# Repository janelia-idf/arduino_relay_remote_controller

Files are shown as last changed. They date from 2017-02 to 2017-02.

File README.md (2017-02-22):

#arduino_relay_remote_controller

Authors:

    Peter Polidoro <polidorop@janelia.hhmi.org>

License:

    BSD

##firmware

Contains the Arduino firmware files. See firmware/README.rst

##host

Contains the code for controlling with a host computer.

###python

See host/python/README.rst

##pcb

Contains the pcb Kicad and gerber files.

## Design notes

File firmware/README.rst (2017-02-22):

Arduino Relay Remote Controller Device Firmware
-----------------------------------------------

Arduino firmware for the arduino_relay_remote_controller device.

For see the INSTALL.rst for installation instructions.

arduino_relay_remote_controller device firmware may be freely distributed
and modified in accordance with the License.

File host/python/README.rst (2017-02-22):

===============================
arduino_relay_remote_controller
===============================

arduino_relay_remote_controller is a python package to control the
Arduino relay remote controller over USB, using the python module, the
command line, or a webpage using a webserver.

Install
-------

See INSTALL.rst

Python Module
-------------

If installed into a python virtual environment, first activate it::

    source ~/virtualenvs/arduino_relay_remote_controller/bin/activate

Use ipython to run or test::

    ipython

Typical usage from an ipython shell often looks like this::

    from arduino_relay_remote_controller import ArduinoRelayRemoteController, ArduinoRelayRemoteControllers

    relay_remote_controllers = ArduinoRelayRemoteControllers()
    device_count = len(relay_remote_controllers)
    if device_count == 0:
        raise RuntimeError('No Arduino relay remote controllers detected, check connections.')
    relay_remote_controllers[0].getDevInfo()

    rrc = relay_remote_controllers[0]
    rrc.getCmds()
    # turn on all relays
    rrc.setAllRelaysOn()
    # turn off all relays
    rrc.setAllRelaysOff()
    # turn on relay 12
    rrc.setRelayOn(12)
    # turn off relay 12
    rrc.setRelayOff(12)
    # turn all board 0 relays on
    rrc.setAllBoardRelaysOn(0)
    # turn all board 0 relays off
    rrc.setAllBoardRelaysOff(0)
    # turn on relay 2 on board 1
    rrc.setBoardRelayOn(1,2)
    # turn on relay 2 on board 1
    rrc.setBoardRelayOff(1,2)

Web Page Controls
-----------------

Open a terminal and run::

    arduino_relay_remote_controller_webserver.py

Open a browser and navigate to::

    http://localhost:5000

Author: Peter Polidoro

This program is free software: you can redistribute it and/or modify
it under the terms of the GNU Lesser General Public License as published by
the Free Software Foundation, either version 3 of the License, or
(at your option) any later version.

This program is distributed in the hope that it will be useful,
but WITHOUT ANY WARRANTY; without even the implied warranty of
MERCHANTABILITY or FITNESS FOR A PARTICULAR PURPOSE.  See the
GNU Lesser General Public License for more details.

You should have received a copy of the GNU Lesser General Public License
along with this program.  If not, see <http://www.gnu.org/licenses/>.

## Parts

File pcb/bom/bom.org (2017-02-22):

# Bill of Materials
| ! | part    | description                      | vendor      | part number      | quantity |   cost |
|---+---------+----------------------------------+-------------+------------------+----------+--------|
|   | PCB     | arduino_relay_remote_control     | pcbuniverse | 1.3              |        1 |   1.00 |
|   | C1      | CAP CER 1UF 25V 10% X7R 1210     | digikey     | 445-13383-1-ND   |        1 |   0.84 |
|   | C2-3    | CAP CER 0.1UF 50V 10% X7R 1210   | digikey     | 478-3586-1-ND    |        2 |   0.39 |
|   | D1-17   | LED GREEN CLEAR 0805 SMD         | digikey     | 160-1179-1-ND    |       17 |   0.35 |
|   | P1      | CONN PWR JACK DC 2.5X5.5 8A T/H  | digikey     | CP-063BH-ND      |        1 |   1.78 |
|   | P1      | POWER SUPPLY SWITCHER 101W 24V   | digikey     | 271-2731-ND      |        1 |  81.38 |
|   | P1      | LINE CORD 3 COND US              | digikey     | 993-1039-ND      |        1 |   3.18 |
|   | P2-3    | CONN MOD JACK R/A 8P8C           | digikey     | RJSAE508002-ND   |        2 |   3.15 |
|   | R1-17   | RES 1.00K OHM 1/2W 1% 1210 SMD   | digikey     | 541-1.00KAACT-ND |       17 |   0.29 |
|   | SHIELD1 | BOARD MCU MEGA2560               | digikey     | 1050-1018-ND     |        1 |  51.91 |
|   | SHIELD1 | CONN HDR VERT 50POS .100" SNGL   | digikey     | SAM1055-50-ND    |        2 |   3.42 |
|   | U1      | IC SW SMART OCTAL LOWSIDE PDSO24 | digikey     | TLE7230GCT-ND    |        2 |   4.62 |
|---+---------+----------------------------------+-------------+------------------+----------+--------|
| # | total   |                                  |             |                  |          | 174.13 |
#+TBLFM: @14$7=(@I$quantity..@II$quantity)*(@I$cost..@II$cost);%.2f;N

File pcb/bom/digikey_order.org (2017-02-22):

# Bill of Materials
| quantity | part number      | ! | part    | description                      | vendor  |   cost |
|----------+------------------+---+---------+----------------------------------+---------+--------|
|       10 | 445-13383-1-ND   |   | C1      | CAP CER 1UF 25V 10% X7R 1210     | digikey |   0.84 |
|       20 | 478-3586-1-ND    |   | C2-3    | CAP CER 0.1UF 50V 10% X7R 1210   | digikey |   0.39 |
|      200 | 160-1179-1-ND    |   | D1-17   | LED GREEN CLEAR 0805 SMD         | digikey |   0.35 |
|       10 | CP-063BH-ND      |   | P1      | CONN PWR JACK DC 2.5X5.5 8A T/H  | digikey |   1.78 |
|       20 | RJSAE508002-ND   |   | P2-3    | CONN MOD JACK R/A 8P8C           | digikey |   3.15 |
|      200 | 541-1.00KAACT-ND |   | R1-17   | RES 1.00K OHM 1/2W 1% 1210 SMD   | digikey |   0.29 |
|       20 | SAM1055-50-ND    |   | SHIELD1 | CONN HDR VERT 50POS .100" SNGL   | digikey |   3.42 |
|       20 | TLE7230GCT-ND    |   | U1      | IC SW SMART OCTAL LOWSIDE PDSO24 | digikey |   4.62 |
|----------+------------------+---+---------+----------------------------------+---------+--------|
|          |                  | # | total   |                                  |         | 170.95 |
#+TBLFM: @10$7=(@I$quantity..@II$quantity)*(@I$cost..@II$cost);%.2f;N

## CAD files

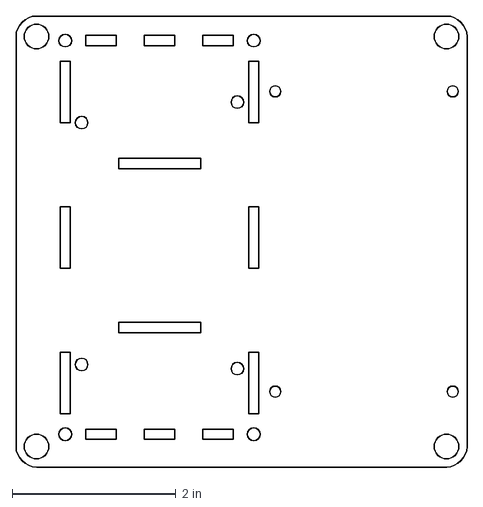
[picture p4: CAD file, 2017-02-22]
enclosure/arduino_relay_remote_controller_enclosure_display.25in.dxf
5.50 x 5.50 in

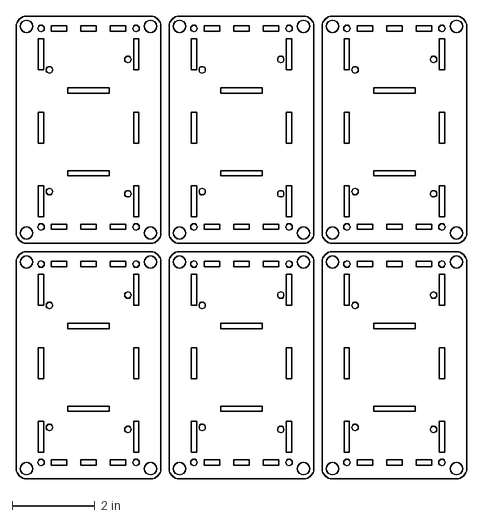
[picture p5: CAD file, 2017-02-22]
enclosure/arduino_relay_remote_controller_enclosure.25in.array.dxf
10.9 x 11.2 in

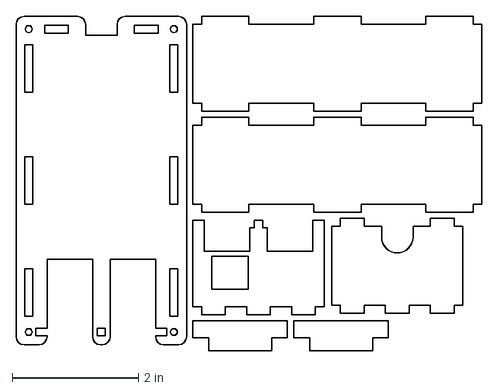
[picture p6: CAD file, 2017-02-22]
enclosure/arduino_relay_remote_controller_enclosure.125in.dxf
7.38 x 5.29 in

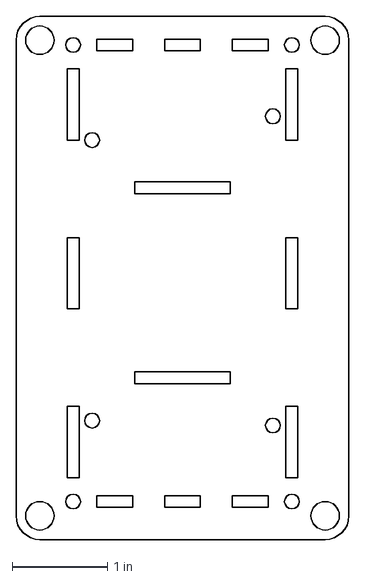
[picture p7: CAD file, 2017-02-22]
enclosure/arduino_relay_remote_controller_enclosure.25in.dxf
3.50 x 5.50 in

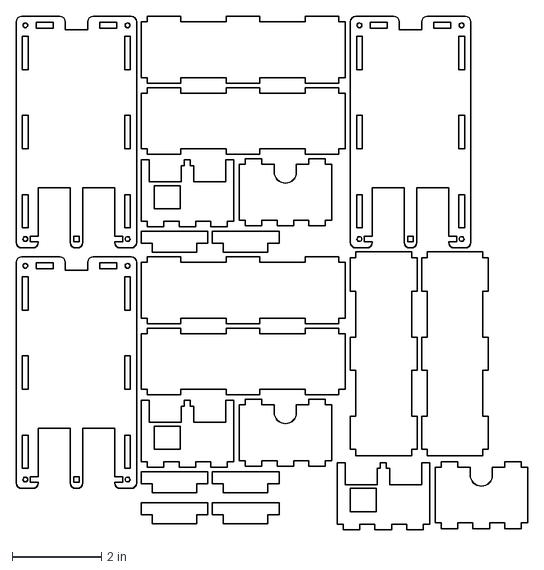
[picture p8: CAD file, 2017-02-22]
enclosure/arduino_relay_remote_controller_enclosure.125in.array.dxf
11.5 x 11.5 in

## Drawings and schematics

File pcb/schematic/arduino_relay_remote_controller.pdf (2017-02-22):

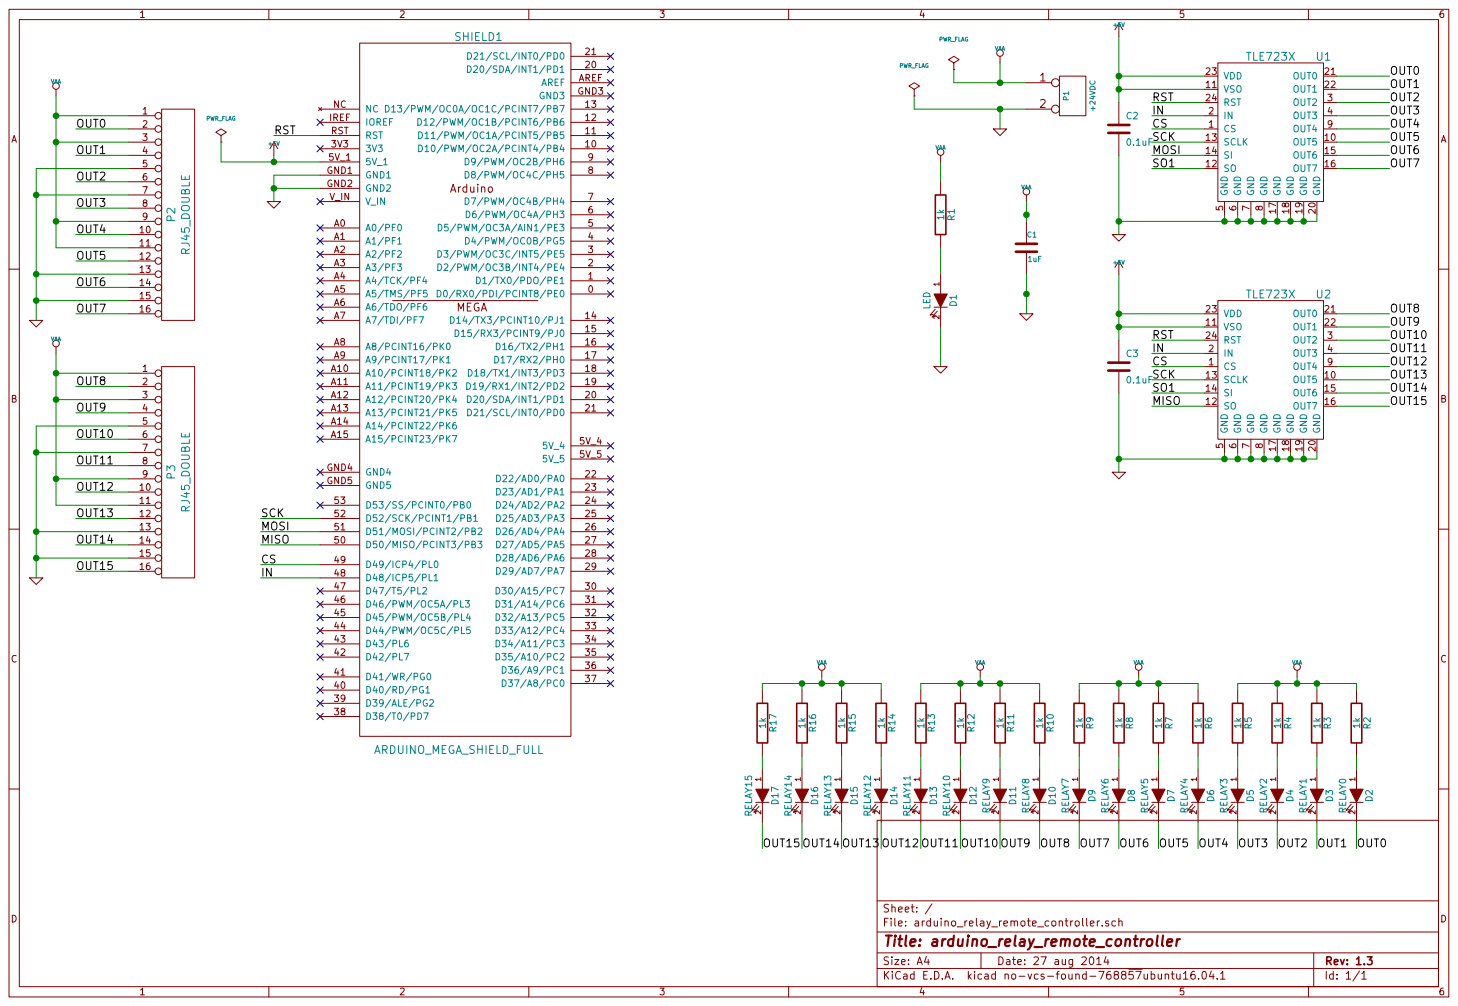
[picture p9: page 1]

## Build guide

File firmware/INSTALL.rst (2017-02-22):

Firmware installation instructions
-----------------------------------

Requirements:

The following libraries should be placed in the arduino sketchbook libraries
directory.

* Streaming              https://bitbucket.org/peterpolidoro/arduino_libs/src
* SerialReceiver         https://bitbucket.org/peterpolidoro/arduino_libs/src
* DictPrinter            https://bitbucket.org/peterpolidoro/arduino_libs/src
* Tle7232g               https://bitbucket.org/peterpolidoro/arduino_libs/src

Build and upload the firmware using the Arduino IDE.

see http://arduino.cc/en/Guide/Environment for instructions on using the IDE.

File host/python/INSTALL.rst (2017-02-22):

arduino_relay_remote_controller installation instructions
------------------------------------------------------

* Create a new virtual environment if necessary::

    virtualenv --system-site-packages ~/virtualenvs/arduino_relay_remote_controller

* Activate a virtual environment::

    source ~/virtualenvs/arduino_relay_remote_controller/bin/activate

* Install dependencies::

    pip install flask --upgrade
    pip install flask-sijax --upgrade

* Clone bitbucket mercurial repositories::

    mkdir ~/mercurial
    cd ~/mercurial
    hg clone https://bitbucket.org/peterpolidoro/python_libs/
    hg clone https://bitbucket.org/peterpolidoro/arduino_relay_remote_controller/

* Install python packages::

    cd ~/mercurial/python_libs/arduino_device
    python cleanup.py
    python setup.py install
    cd ~/mercurial/arduino_relay_remote_controller/host/python
    python cleanup.py
    python setup.py install

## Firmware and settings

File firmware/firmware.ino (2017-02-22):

#include <SPI.h>
#include <Streaming.h>
#include <EEPROM.h>
#include <util/atomic.h>

#include "SerialReceiver.h"
#include "DictPrinter.h"
#include "Tle7232g.h"

#include "constants.h"
#include "SystemState.h"
#include "MessageHandler.h"

void setup() {
    Serial.begin(constants::baudrate);
    systemState.initialize();
}

void loop() {
    messageHandler.processMsg();
}

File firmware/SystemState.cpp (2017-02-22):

#if defined(ARDUINO) && ARDUINO >= 100
#include "Arduino.h"
#else
#include "WProgram.h"
#endif
#include "string.h"
#include "SystemState.h"

SystemState::SystemState() {
  setErrMsg("");
}

void SystemState::setErrMsg(char *msg) {
  strncpy(errMsg,msg,SYS_ERR_BUF_SZ);
}

void SystemState::initialize() {
  relayDriver = TLE7232G(constants::relayDriverCsPin,constants::relayDriverInPin);

  // Initialize SPI:
  SPI.setDataMode(SPI_MODE1);
  SPI.setClockDivider(SPI_CLOCK_DIV4);
  SPI.setBitOrder(MSBFIRST);
  SPI.begin();

  relayDriver.init(constants::relayDriverDeviceCount);
  setAllRelaysOff();

}

bool SystemState::setRelays(uint32_t relays) {
  relayDriver.setChannels(relays);
  return true;
}

bool SystemState::setRelayOn(int relay) {
  relayDriver.setChannelOn(relay);
  return true;
}

bool SystemState::setRelayOff(int relay) {
  relayDriver.setChannelOff(relay);
  return true;
}

bool SystemState::setAllRelaysOn() {
  uint32_t relays = 0;
  relays = ~relays;
  setRelays(relays);
  return true;
}

bool SystemState::setAllRelaysOff() {
  uint32_t relays = 0;
  setRelays(relays);
  return true;
}

bool SystemState::setBoardRelays(int board, uint32_t board_relays) {
  uint32_t relays = board_relays << board*constants::boardRelayCount;
  setRelays(relays);
  return true;
}

bool SystemState::setBoardRelayOn(int board, int board_relay) {
  int relay = board*constants::boardRelayCount + board_relay;
  setRelayOn(relay);
  return true;
}

bool SystemState::setBoardRelayOff(int board, int board_relay) {
  int relay = board*constants::boardRelayCount + board_relay;
  setRelayOff(relay);
  return true;
}

bool SystemState::setAllBoardRelaysOn(int board) {
  int relay;
  int relay_offset = board*constants::boardRelayCount;
  for (int board_relay=0; board_relay<constants::boardRelayCount; board_relay++) {
    relay = relay_offset + board_relay;
    setRelayOn(relay);
  };
  return true;
}

bool SystemState::setAllBoardRelaysOff(int board) {
  int relay;
  int relay_offset = board*constants::boardRelayCount;
  for (int board_relay=0; board_relay<constants::boardRelayCount; board_relay++) {
    relay = relay_offset + board_relay;
    setRelayOff(relay);
  };
  return true;
}

bool SystemState::toggleRelay(int relay) {
  uint32_t channels_on = relayDriver.getChannelsOn();
  uint32_t bit = 1;
  bit = bit << relay;
  channels_on = channels_on ^ bit;
  relayDriver.setChannels(channels_on);
  return true;
}

SystemState systemState;

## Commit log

2017-02-22 Initial commit.
    [$savepcb.brd, arduino_relay_remote_controller.brd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]
2017-02-22 Added schematic pdf.
